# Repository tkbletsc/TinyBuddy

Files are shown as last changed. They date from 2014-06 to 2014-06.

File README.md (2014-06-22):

TinyBuddy
=========

A host PCB for the ATtiny84 microcontroller.  Features two buttons, an activity LED, 16MHz crystal for accurate timekeeping, and USB or DC barrel jack for power.  The Rev2 design using entirely through-hole parts for easy construction.  Can be fabricated for about $7 through OSH Park.

Rev1: A micro-USB powered prototype.

- Ergonomic problem: instinct is to use it upside down
- Surface mount micro USB sucks to solder
- Programming ribbon cable presses up against reset button
- Pin silkscreens often cut off
- Labels of S7 and S8 reversed (duh!)

Rev2:

- Reoriented text and components to be used with chip facing away
- Switched to DC barrel connector for power
- Rearranged components to separate programming port, arranged things
better
- Design now uses entirely through-hole components
- Tweaked pin silk screens
- Fixed button labels

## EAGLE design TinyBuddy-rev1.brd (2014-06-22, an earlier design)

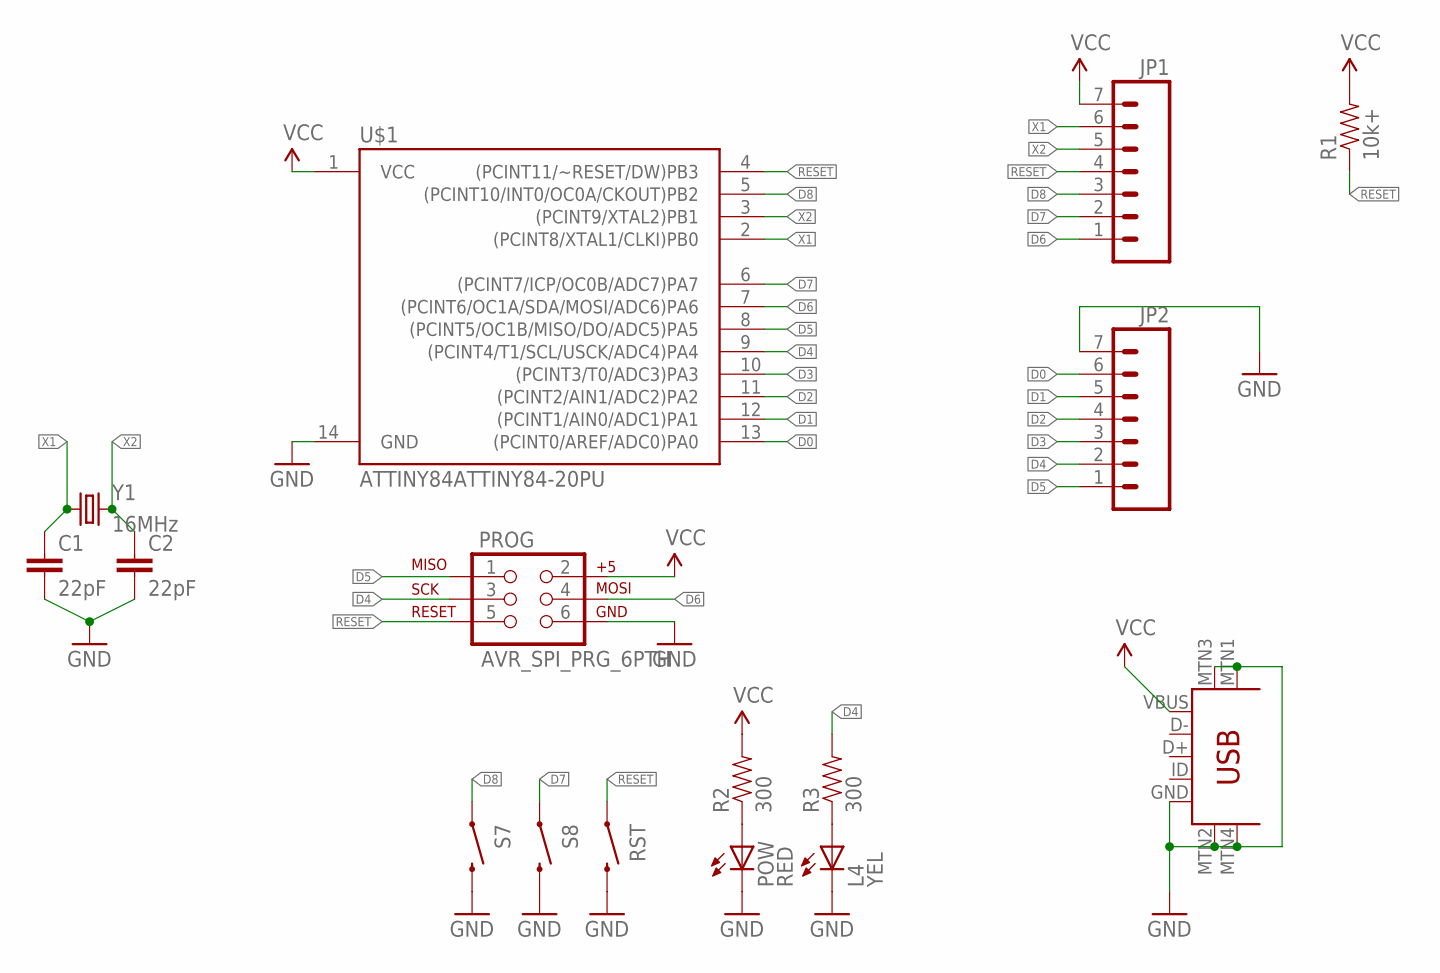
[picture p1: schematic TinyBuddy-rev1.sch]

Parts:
C1, C2: 22pF; CAP-PTH-SMALL
JP1, JP2: M07NOSILK; 1X07_NOSILK
L4: YEL; LED3MM
POW: RED; LED3MM
PROG: AVR_SPI_PRG_6PTH; 2X3
R1: 10k+; 1/6W-RES
R2, R3: 300; 1/6W-RES
RST: SWITCH-MOMENTARY-2PTH; TACTILE-PTH
S7, S8: SWITCH-MOMENTARY-2PTH; TACTILE-PTH
U$1: ATTINY84ATTINY84-20PU; DIL14
U$2: USB-MINIB-5PIN; USB-MINIB
Y1: 16MHz; HC49US

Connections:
D0: JP2.6, U$1.13 ((PCINT0/AREF/ADC0)PA0)
D1: JP2.5, U$1.12 ((PCINT1/AIN0/ADC1)PA1)
D2: JP2.4, U$1.11 ((PCINT2/AIN1/ADC2)PA2)
D3: JP2.3, U$1.10 ((PCINT3/T0/ADC3)PA3)
D4: JP2.2, PROG.3, R3.2, U$1.9 ((PCINT4/T1/SCL/USCK/ADC4)PA4)
D5: JP2.1, PROG.1, U$1.8 ((PCINT5/OC1B/MISO/DO/ADC5)PA5)
D6: JP1.1, PROG.4, U$1.7 ((PCINT6/OC1A/SDA/MOSI/ADC6)PA6)
D7: JP1.2, S8.1, U$1.6 ((PCINT7/ICP/OC0B/ADC7)PA7)
D8: JP1.3, S7.1, U$1.5 ((PCINT10/INT0/OC0A/CKOUT)PB2)
GND: C1.2, C2.2, JP2.7, L4.K (C), POW.K (C), PROG.6, RST.3 (2), S7.3 (2), S8.3 (2), U$1.14 (GND), U$2.GND, U$2.MTN1 (MTN2), U$2.MTN2 (MTN3), U$2.MTN3 (MTN1), U$2.MTN4
unnamed: POW.A, R2.1
unnamed: L4.A, R3.1
RESET: JP1.4, PROG.5, R1.1, RST.1, U$1.4 ((PCINT11/~RESET/DW)PB3)
VCC: JP1.7, PROG.2, R1.2, R2.2, U$1.1 (VCC), U$2.VBUS
X1: C1.1, JP1.6, U$1.2 ((PCINT8/XTAL1/CLKI)PB0), Y1.1
X2: C2.1, JP1.5, U$1.3 ((PCINT9/XTAL2)PB1), Y1.2

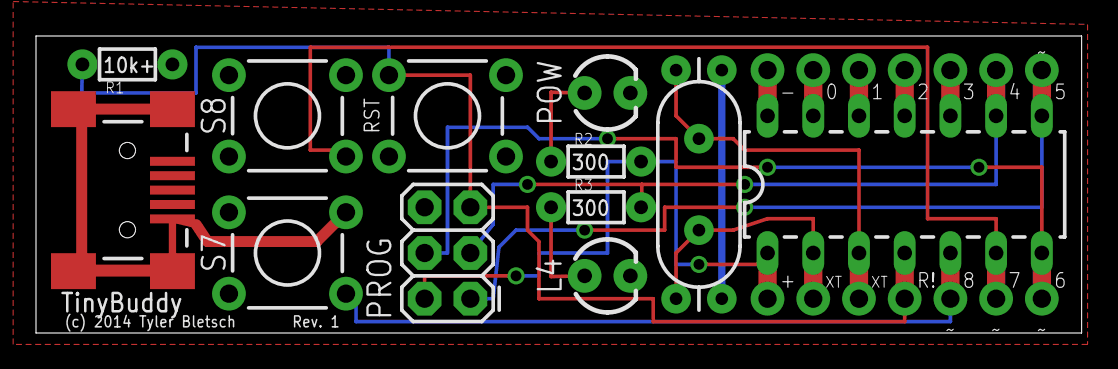
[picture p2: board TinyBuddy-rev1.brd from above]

Board: 2 copper layers, 58.1 x 16.5 mm, 16 parts (0 on the bottom side), 16 nets.

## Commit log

2014-06-22 Initial import
    Rev1: A micro-USB powered prototype.
    - Ergonomic problem: instinct is to use it upside down
    - Surface mount micro USB sucks to solder
    - Programming ribbon cable presses up against reset button
    - Pin silkscreens often cut off
    Rev2:
    - Reoriented text and components to be used with chip facing away
    - Switched to DC barrel connector for power
    - Rearranged components to separate programming port, arranged things
    better
    - Design now uses entirely through-hole components
    - Tweaked pin silk screens
    [TinyBuddy-rev1.sch, TinyBuddy-rev2.brd, TinyBuddy-rev2.sch]
2014-06-22 Forgot to include rev1 brd file
    [TinyBuddy-rev1.brd]

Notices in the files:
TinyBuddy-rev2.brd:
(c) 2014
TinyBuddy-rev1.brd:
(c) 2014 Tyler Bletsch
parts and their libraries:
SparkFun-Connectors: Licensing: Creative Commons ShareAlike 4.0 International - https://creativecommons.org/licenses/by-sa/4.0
